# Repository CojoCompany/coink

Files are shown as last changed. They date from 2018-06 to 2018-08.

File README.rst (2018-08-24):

Coink logo

Coink
=====

An IoT piggy bank.

Read `the documentation <https://coink.readthedocs.io/>`_ to know how it works
and how to build your own Coink!

`See Coink in action! <https://www.youtube.com/watch?v=FcyVjBXFm-M>`_



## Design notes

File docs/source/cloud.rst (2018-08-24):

.. index:: cloud

*****************
Cloud integration
*****************

.. index:: flashing

Flashing the NodeMCU
====================

Before running our cloud server, we definitely want to actually upload the
Coink MicroPython code to the NodeMCU board.

This is actually very simple, but we do need to have some dependencies
installed: ``screen`` and ``ampy``. Once we have those, we can simply connect
our board to our computer with an USB cable and::

   ./flash.sh

This Bash script will upload all the necessary code to our board.

.. index:: coink-server

Coink server
============

Running the Coink server is necessary to appropriately process the data and
classify the coins in "the cloud", whether it is your own computer or an actual
cloud service.

The server is implemented with `Flask`_ and requires some other Python packages
to run. Fortunately, `Pipenv`_ helps us to create the required virtual environment with all dependencies installed::

   pipenv sync

If we want to have all the development dependencies installed, use instead::

   pipenv sync --dev

Our prototype is designed to work within a local area network, where we have
the NodeMCU and our computer connected to the same WiFi network (probably our
home network). In order to be able to do so, we need to copy the contents of
the ``config.template.json`` to a new ``config.json`` file, that would look
like this:

.. literalinclude:: ../../config.template.json

We need to modify the ``"wifi"`` fields with our network name and password.

Note that there is another section to configure the ``"server"``. There, we
need to put our computer IP address and a port, where our server will be
listening on.

.. note:: The access port should be just a free port, try it for example with
   5000

Then we can run the server with Pipenv::

   pipenv run python server.py

If everything went well, you should be able to access the configured server
with your web browser. To do so, visit
``http://your-defined-host:your-defined-port/`` (i.e.:
``http://192.168.43.110:5000/``), you should see the Coink server page:

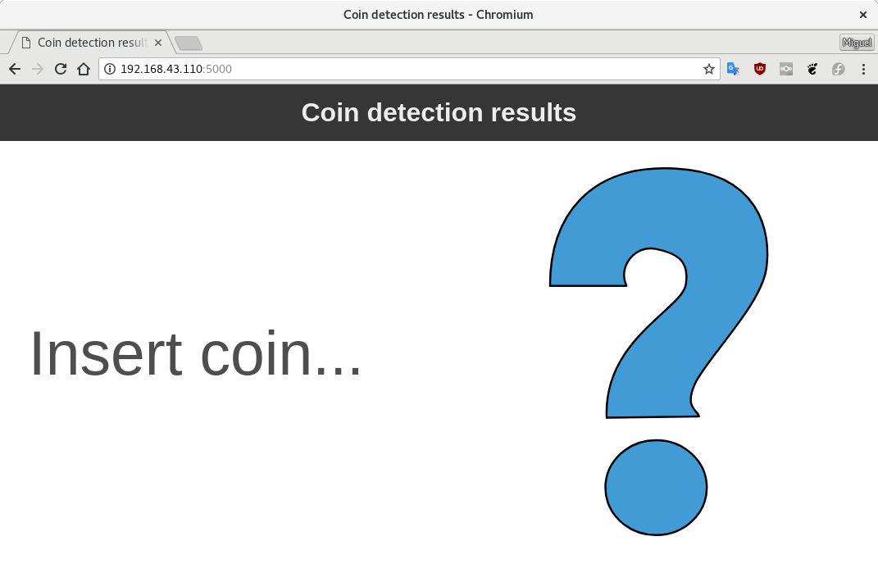
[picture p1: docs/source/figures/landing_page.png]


   Coink landing page.

Now go ahead and insert one coin into your Coink! ^^

.. raw:: html

   <div style="position: relative; padding-bottom: 60%; height: 0;">
     <iframe src="https://www.youtube-nocookie.com/embed/FcyVjBXFm-M?rel=0" frameborder="0" allow="autoplay; encrypted-media" allowfullscreen width="100%" style="position: absolute; top: 0; left: 0; width: 100%; height: 100%">
     </iframe>
   </div>

.. index:: thingspeak

Thingspeak
==========

Integrating Coink with an external cloud service like Thingspeak is very
straight forward thanks to their public RESTful API. We just need to write a
couple of lines of code to process and visualize the data appropriately.

The following code snippet plots the daily savings in the last couple of days:

.. code:: matlab

   [data, time] = thingSpeakRead(516536, 'Fields', [1], 'NumDays', 7);
   data = timetable(time, data)
   data = retime(data, 'daily', 'sum')
   bar(data.time, data.Variables, 'FaceColor', [1 .5 0])

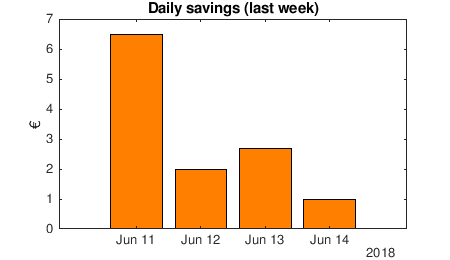
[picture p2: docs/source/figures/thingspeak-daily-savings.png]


The following code snippet plots the total accumulated savings:

.. code:: matlab

   [data, time] = thingSpeakRead(516536, 'Fields', [1], 'NumDays', 365);
   curve = cumsum(data);
   area(time, curve, 'FaceColor', [1 .5 0]);
   title(strcat('Total savings: ', num2str(sum(data), '%.2f'), ' €'));
   ylabel('€');

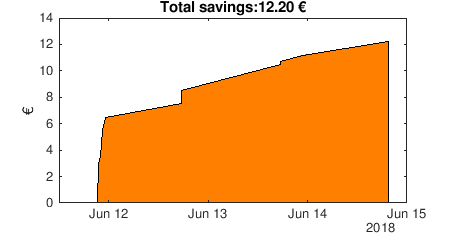
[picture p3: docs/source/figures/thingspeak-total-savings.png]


Note that the code above assumes that the Thingspeak channel was created to
ingest a single field, which corresponds to the coin that was detected on
insertion. The code then sums by day or calculates the total cumulated sum.

References
==========

.. target-notes::

.. _`Flask`:
   http://flask.pocoo.org/
.. _`Pipenv`:
   https://pipenv.readthedocs.io/

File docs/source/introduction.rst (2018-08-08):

.. index:: introduction

************
Introduction
************

.. index:: abstract

What is Coink?
--------------

Coink is an IoT piggy bank.

In the 21st Century piggy banks can be very easily connected to the cloud and
become part of the rapidly growing Internet of Things.

Having automatic reports of your savings online is not only very convenient but
can also make saving fun for kids! With Coink you can have real-time graphics
with your cumulative savings as well as the recent daily savings to track your
progress.

Adults may use it as well, not only for fun, but to help them quit smoking, for
example, keeping track of the money they save each day. Or in bars and
restaurants, to keep track of the tips they get each day.

Of course the magnetic coin detection system can be used elsewhere: in vending
machines, arcade game machines... The cloud-connected piggy bank is just an
application.

.. index:: materials

What do we need?
----------------

In order to build Coink, we will need:

- A wooden box.
- A `3D-printed ramp`_.
- A magnet attached to the ramp, that generates a static magnetic field.
- A `3D Magnetic Sensor 2GO`_ board from Infineon, that will detect the changes
  on the magnetic field when a coin passes through the ramp and in between the
  magnet and the sensor.
- An ESP8266-based board, in particular a `NodeMCU development kit`_, that
  reads the data from the 3D magnetic sensor through I2C and sends it through
  WiFi to the cloud.
- A `cloud server`_ that analyzes the raw data and identifies the
  different coins.



   Coink project overview

References
==========

.. target-notes::

.. _`3D-printed ramp`:
   https://github.com/CojoCompany/coink/blob/master/3d/ramp.stl
.. _`3D Magnetic Sensor 2GO`:
   https://www.infineon.com/cms/en/product/sensor/magnetic-position-sensor/3d-magnetic-sensor/tle493d-a2b6-ms2go/
.. _`NodeMCU development kit`:
   https://github.com/nodemcu/nodemcu-devkit-v1.0
.. _`cloud server`:
   https://github.com/CojoCompany/coink

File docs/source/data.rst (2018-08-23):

.. index:: data

****
Data
****

.. index:: visualization

Visualization
=============

If we visualize the sensor readings during one second, when a coin is passing
by, we note that there is little time (around 50 milliseconds) to get useful
data:

.. plot::
   :align: center
   :context:

   from analysis import read_data
   from matplotlib import pyplot

   pyplot.style.use('seaborn')

   read_data('../../data/1-0.csv')[:1].plot()

Each of the axis has a different iddle-state reading, so we can normalize the
readings by first dividing by the average iddle-state reading and then
substracting 1 to have an iddle-state reading of 0 in all axis and also to have
data curves that represent relative variations of the magnetic field instead of
absolute.

After doing this normalization we can visualize our region of interest for both
1 € and 2 € coins:

.. plot::
   :align: center
   :context: close-figs

   from analysis import load_data

   c1 = load_data(1, path='../../data')
   c2 = load_data(2, path='../../data')
   c1[0].plot(title='1 €')
   c2[0].plot(title='2 €')

.. index:: differences

Differences
===========

Having a look at the previous curves we might notice some differences between
the 1 € and 2 € curves. Among them we might notice a small difference in the
time span. Although that makes sense (the 2 € coin has a bigger diameter than
the 1 € coin) and we would expect it to alter the magnetic field for a longer
period, this is assuming the speed is the same for both coins. That, of course,
is not very reliable, as we could simply insert coins with higher speed when
pushing them down the ramp. Therefore, we will ignore differences in the x-axis
(time) and focus on the y-axis (magnetic field relative variations).

In order to be able to compare curves and try to differenciate among different
coins, we did some simple feature engineering to try to extract some curve
features that are relevant and easy to compare/match against known profiles:



   Engineered features.

min_[axis]
  Represents the absolute minimum value, for the given axis.

d0_[axis]
  Represents the maximum positive increase since the last rolling minimum from
  the iddle state and until the absolute minimum is reached, for the given
  axis.

l0_[axis]
  Represents the low value where ``d0_[axis]`` started, for the given axis.

Although the differences for those engineered features might seem obvious for
the curves shown above, we want to make sure that the differences are
significant on average for all the data we gathered.

To visualize these differences we can use box plots for all ``min``, ``l0`` and
``d0`` features, for all axis as well:

.. plot::
   :align: center
   :context: close-figs

   from analysis import compare_d0
   from analysis import compare_l0
   from analysis import compare_min
   from analysis import data_summary

   df = data_summary(c1, c2)
   compare_min(df)
   compare_d0(df)
   compare_l0(df)

We can see there are many significant differences between the two coins.
Although we could use only the most significant among them it is better to
simply use all features. Matching against the average plus some expected
deviation we can not only differenciate between 1 € and 2 € coins, but also
detect unexpected (potentially fake coins) readings.

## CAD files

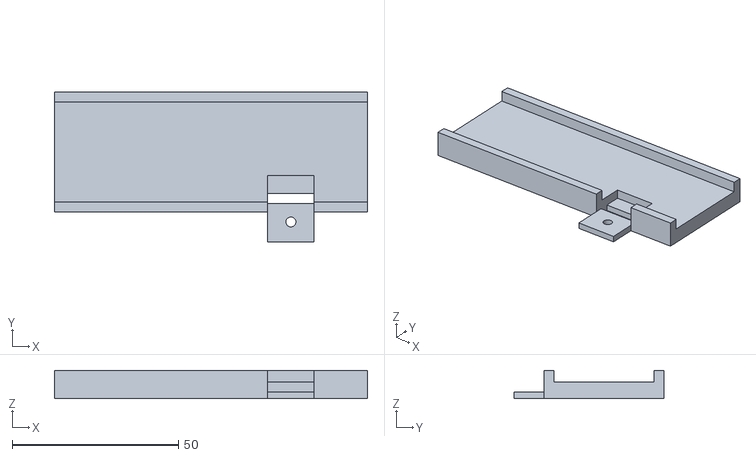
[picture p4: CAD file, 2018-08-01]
3d/ramp.stl
94.0 x 45.0 x 8.50

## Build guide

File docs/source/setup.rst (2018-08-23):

.. index:: setup

*****
Setup
*****

.. index:: board

Board
=====

We use an ESP8266-based board, in particular a `NodeMCU development kit`_.

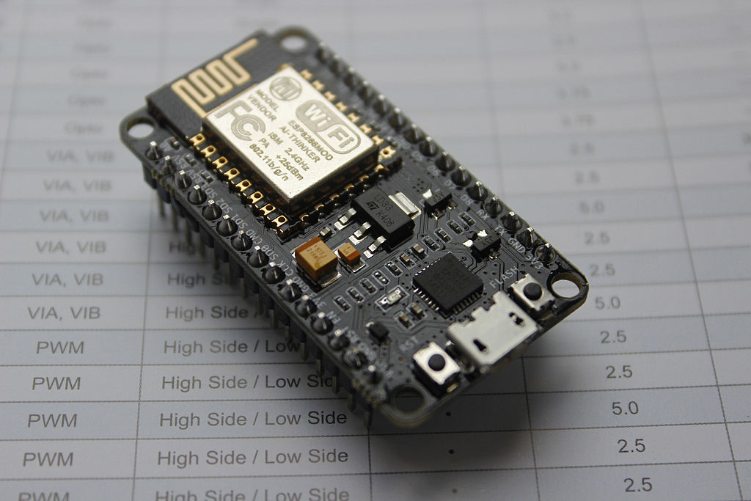
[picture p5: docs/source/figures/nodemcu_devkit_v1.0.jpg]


   NodeMCU development kit.

It is a very cheap, but powerful board.

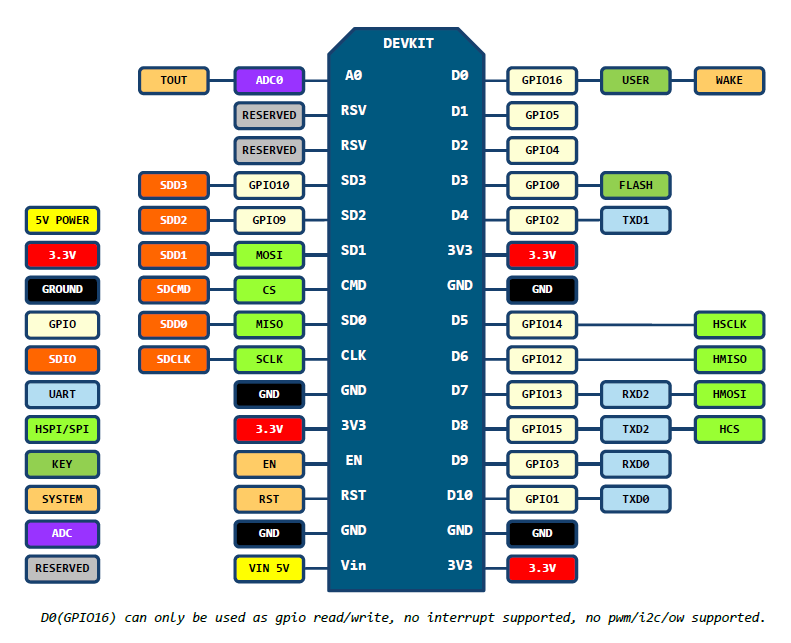
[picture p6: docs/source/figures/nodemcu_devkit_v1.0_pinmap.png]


   NodeMCU development kit pinout.

.. index:: micropython

MicroPython
===========

We use the Python programming language or, more accurately, the `MicroPython`_
programming language. Not only it is a beautiful language, but also implements
an HTTP stack that will ease the process of communicating with a remote server
in any IoT project.

In order to start using MicroPython, we need to `load the MicroPython firmware
onto the ESP8266 board
<https://docs.micropython.org/en/latest/esp8266/esp8266/tutorial/intro.html>`_
first.

Flashing the firmware
---------------------

We need to make sure we have the required permissions to flash the device.
Either::

   sudo usermod -a -G dialout $USER

Or, to avoid the need to log out of your session::

   sudo echo 'ATTRS{idVendor}=="1a86", ATTRS{idProduct}=="7523", MODE="0666"'> /etc/udev/rules.d/99-nodemcu.rules
   sudo udevadm control --reload-rules

.. note:: You might need to adjust the ``idVendor`` and ``idProduct`` depending
   on what you see with ``dmesg`` when connecting the device.

We use `esptool`_ to reflash the device, which is very easy to install with::

   pip install --user esptool

Then, reconnect the device and erase its flash memory with::

   esptool.py --port /dev/ttyUSB0 erase_flash

Download the `latest MicroPython firmware for ESP8266 boards
<https://micropython.org/download#esp8266>`_ and flash it with::

   esptool.py --port /dev/ttyUSB0 --baud 460800 write_flash --flash_size=detect 0 esp8266-20180511-v1.9.4.bin

Testing the REPL
----------------

Once the MicroPython firmware is on the device we can access the REPL (Python
prompt) over serial with a 115000 baudrate::

   screen /dev/ttyUSB0 115200

If everything went well we should see a ``>>>`` (if not, try to press "enter").
You may now try to execute a simple ``print()`` call, which will be executed in
the board itself:



   MicroPython REPL.

.. index:: sensor

Sensor
======

The ESP8266 board is connected to the sensor through an I2C bus, in particular,
using D1 (GPIO5) for the clock and D2 (GPIO4) for the data transmission. The
sensor is powered with the ESP8266 board directly, using its 3V3 and GND pins.

Once the sensor is connected to the board we can check the I2C connection by
simply:

.. code:: python

   from machine import I2C
   from machine import Pin

   i2c = I2C(scl=Pin(5), sda=Pin(4), freq=400000)
   devices = i2c.scan()
   print(devices)

Which should print a non-empty list.

References
==========

.. target-notes::

.. _`esptool`:
   https://github.com/espressif/esptool/
.. _`MicroPython`:
   https://docs.micropython.org/
.. _`NodeMCU development kit`:
   https://github.com/nodemcu/nodemcu-devkit-v1.0

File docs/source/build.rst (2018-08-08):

.. index:: build

*****
Build
*****

.. index:: ramp

Ramp
====

Coink is actually very easy to build. First we need the ramp to insert the
coins. The ramp is a 3D design that can be very easily printed with any FDM 3D
printer (or any other more-advance 3D printer if you have access to it).

.. raw:: html

   <div style="position: relative; padding-bottom: 60%; height: 0;">
     <iframe src="https://render.githubusercontent.com/view/solid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" width="100%" style="position: absolute; top: 0; left: 0; width: 100%; height: 100%">
     </iframe>
   </div>

The 3D design is very simple but, in turn, we need to do some work before using
it. First, we need to glue some plastic sheets to cover the inner parts of the
ramp. This way we avoid the coin bumping into any disturbances around the
sensor board, where the ramp is not continuous:

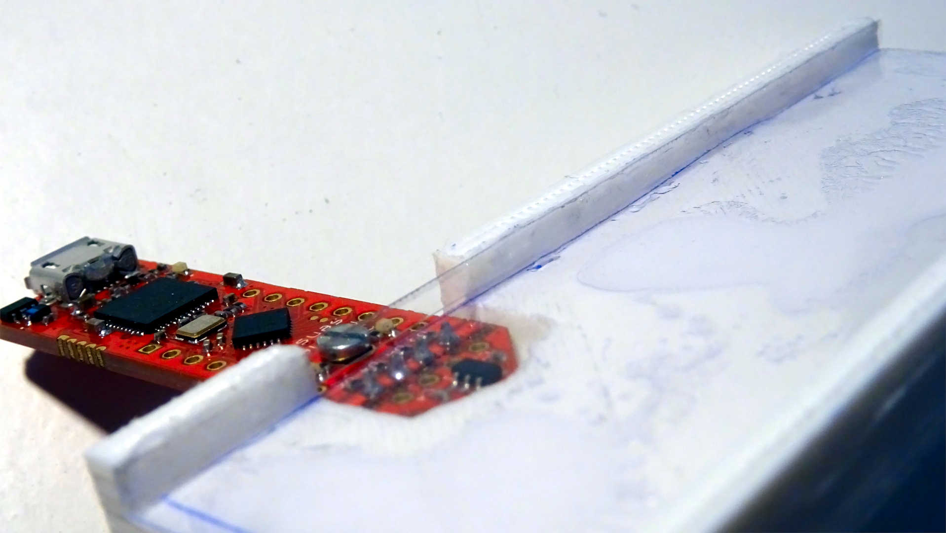
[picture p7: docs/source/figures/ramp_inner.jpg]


   Plastic sheets covering the inner parts of the ramp.

Then we need to cover the outter part of the ramp by glueing another plastic
sheet. We will glue our magnet (in orange) there, just in front of the sensor
board. Any magnet will do, we just need to make sure it is not too powerful, or
the coins will get stuck in the ramp!

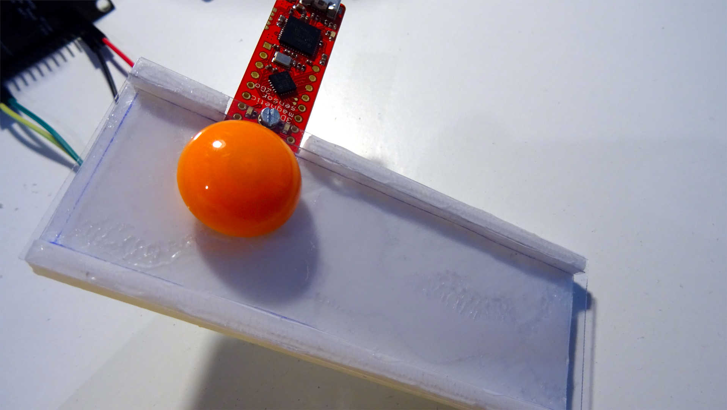
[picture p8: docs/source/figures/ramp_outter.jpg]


   Plastic sheet covering the outter part of the ramp and magnet attached to
   it.

.. index:: box

Box
===

The piggy bank can be made with a small wooden box. Wood is easy to work with,
which is important as we will need to create a hole for the ramp in the box:

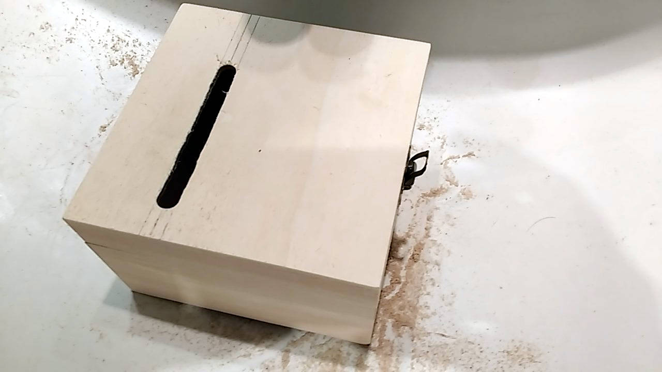
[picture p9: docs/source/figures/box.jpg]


   Wooden box with a hole for the ramp.

Once we have the hole, we can very easily glue the ramp to the box with some
epoxy to make sure it does not move.

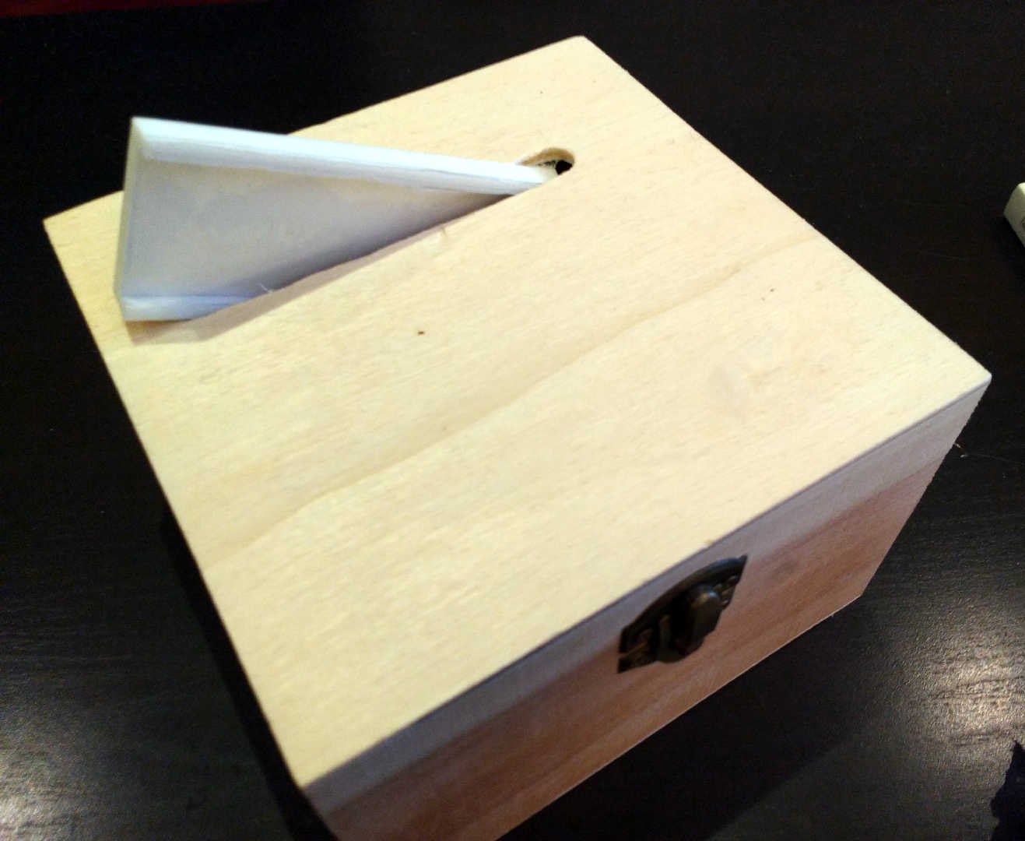
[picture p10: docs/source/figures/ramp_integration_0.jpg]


   Ramp glued to the box.

Even if obvious, we should make sure the magnet and the magnetic sensor board
both fit inside the box before glueing the ramp!

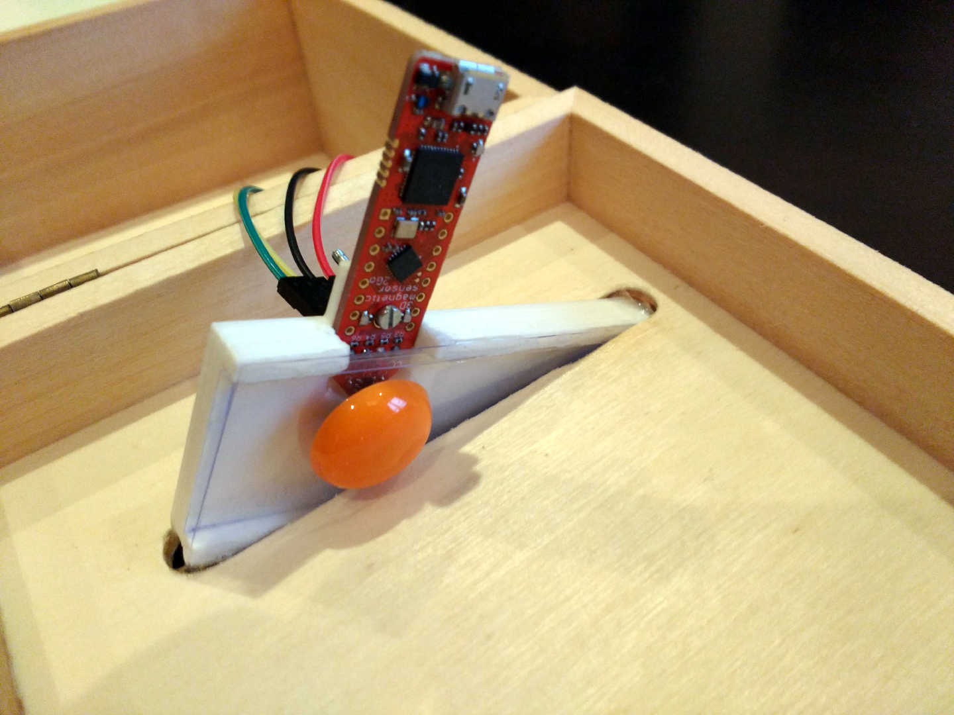
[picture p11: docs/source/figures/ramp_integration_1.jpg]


   Detail of the ramp inside the box.

Once the ramp is fixed, we only need to stick the rest of the components to the
lid:

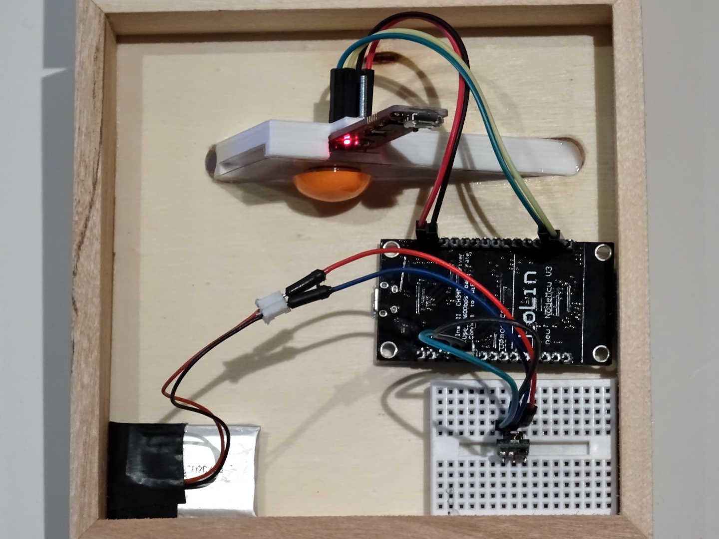
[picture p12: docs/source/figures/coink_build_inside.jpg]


   All the required components fixed and the system powered!

Note that we added a simple power circuit consisting of:

- A LiPo battery (single cell).
- A 3.3 V step-down DC-DC converter mounted on the breadboard.

The output of the converter directly powers the board at 3.3 V.

.. index:: wiring

Wiring
======

Wiring the magnetic sensor board and the NodeMCU boils down to connect only 4 wires:

===========  ===================
NodeMCU pin  Magnetic sensor pin
===========  ===================
D1 (GPIO5)   SDA (P2.10)
D2 (GPIO4)   SCL (P2.11)
3V3          3V3 (P1.0)
GND          GND
===========  ===================

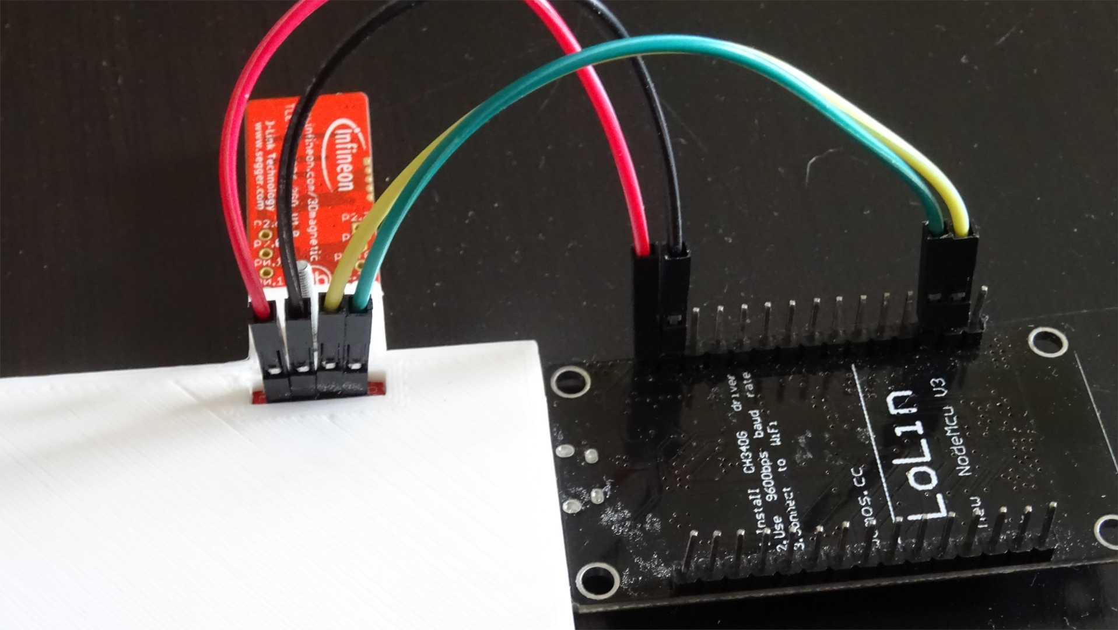
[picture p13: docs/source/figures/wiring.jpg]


   NodeMCU and magnetic sensor wiring.

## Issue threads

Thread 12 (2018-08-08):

Document battery connection

cua-cua, 2018-08-08:
http://henrysbench.capnfatz.com/henrys-bench/arduino-projects-tips-and-more/powering-the-esp-12e-nodemcu-development-board/

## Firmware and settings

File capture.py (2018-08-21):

import json
import sys
import time
import array

import urequests

import machine
from machine import I2C
from machine import Pin
from machine import Signal
from network import WLAN
from network import STA_IF


scan_address = 53

write_address = 0x6a
read_address = 0x6b

register_config = 0x10
register_mod1 = 0x11

reply = bytearray(7)
trigger = 1 << 7
request = bytearray([read_address, trigger + 0x00])

num_measures= 256

ring = array.array('h', (0 for i in range(4 * num_measures)))


def twos_complement(val, bits):
    if (val & (1 << (bits - 1))) != 0:
        val = val - (1 << bits)
    return val


def read_registers(i2c):

    i2c.start()
    ack = i2c.write(request)
    i2c.readinto(reply)
    i2c.stop()

    return reply, ack


def write_register(i2c, register, value):
    """
    Write a register with the given value.
    """
    message = bytearray([write_address, register, value])
    i2c.start()
    ack = i2c.write(message)
    i2c.stop()
    if not ack == 3:
        message = 'Writing register failed after {} bytes!\n'
        sys.stderr.write(message.format(ack))


def read_sensor(i2c):
    reply, ack = read_registers(i2c)

    x_high = reply[0]
    x_low = (reply[4] >> 4)
    y_high = reply[1]
    y_low = (reply[4] & 0x0F)
    z_high = reply[2]
    z_low = (reply[5] & 0x0F)
    t_high = reply[3]
    t_low = (reply[5] >> 6)

    x = twos_complement((x_high << 4) + x_low, 12)
    y = twos_complement((y_high << 4) + y_low, 12)
    z = twos_complement((z_high << 4) + z_low, 12)
    t = twos_complement((t_high << 2) + t_low, 10)

    return reply, (x, y, z, t), ack


def get_sensor_values(i2c):
    for i in range(100):
        reply, readings, ack = read_sensor(i2c)
        status = reply[6]
        pd0 = bool(status & 0b100)
        if not pd0:
            message = 'Power-down flag 0 (PD0) was zero! Retrying...\n'
            sys.stderr.write(message.format(ack))
            continue
        pd3 = bool(status & 0b1000)
        if not pd3:
            message = 'Power-down flag 3 (PD3) was zero! Retrying...\n'
            sys.stderr.write(message.format(ack))
            continue
        tbit = bool(status & 0b10000)
        if tbit:
            message = 'T-bit was one! Retrying...\n'
            sys.stderr.write(message.format(ack))
            continue
        frame_counter = status & 0b11
        break
    return reply, readings, ack, i, pd0, frame_counter


class Node:
    def __init__(self):
        """
        Initialize the node.

        Performs the hardware setup and configuration loading from
        `config.json` file.
        """
        machine.freq(160000000)

        self.led = Signal(Pin(2, Pin.OUT), invert=True)
        self.led.off()

        self.i2c = I2C(scl=Pin(5), sda=Pin(4), freq=400000)

        self.station = WLAN(STA_IF)

        self.config = json.load(open('config.json'))

        self.countdown = None

    def setup_sensor(self):
        """
        Configure the sensor to use Master Controlled Mode.

        Also, enable clock stretching and disable interruptions. Sensor read
        out is suppressed during ongoing ADC conversions.

        Returns
        -------
        The number of acklowledges the sensor sent back. Should be 3.
        """
        devices = self.i2c.scan()
        if not scan_address in devices:
            message = 'Sensor "{}" does not seem to be available!\n'
            sys.stderr.write(message.format(scan_address))
            return

        write_register(self.i2c, register_config, 0b00001001)
        write_register(self.i2c, register_mod1, 0b10000101)

    def connect_wifi(self):
        """
        Connect the node to a wireless network.

        The wireless network must be defined in the `config.json` file.
        """
        self.station.active(True)
        config = self.config['wifi']
        self.station.connect(config['ssid'], config['password'])
        for i in range(10):
            if self.station.isconnected():
                break
            sys.stdout.write('Waiting for connection to be established...\n')
            time.sleep(1)
        else:
            message = 'Could not establish connection...\n'
            sys.stderr.write(message.format(ack))
            led.on()

    def update_savings(self, savings):
        """
        Update the remote servers with the new savings.
        """
        url = 'https://api.thingspeak.com/update'
        url += '?api_key={key}&field1={savings}'
        url = url.format(key=self.config['thingspeak_key'], savings=savings)
        reply = urequests.get(url)
        return reply

    def send_readings(self):
        """
        Send magnetic sensor values from a file to the server detailed
        on the file config.json.
        """
        url = 'http://{host}:{port}/analyze'.format(**self.config['server'])
        response = urequests.post(url, data=bytearray(ring))

    def callibrate(self):
        """
        Callibrate the sensor and set the threshold for coin detection.
        """
        total = 0
        count = 10
        for i in range(count):
            reply, (x, y, z, t), ack = read_sensor(self.i2c)
            total += x
        self.threshold = 0.8 * total / count

    def loop(self):
        """
        Read and send coin values forever.
        """
        i = 0
        while True:
            i = i % num_measures
            reply, (x, y, z, t), ack = read_sensor(self.i2c)
            # Make sure we never try to store a value higher than the size of
            # the `t_array` elements
            position = i * 4
            ring[position] = time.ticks_us() % 65536
            ring[position + 1] = x
            ring[position + 2] = y
            ring[position + 3] = z
            if self.countdown is None:
                if x < self.threshold:
                    self.countdown = 150
            else:
                self.countdown -= 1
                if self.countdown == 0:
                    print('Sending readings...')
                    self.send_readings()
                    print('Readings sent!')
                    self.countdown = None
            i += 1

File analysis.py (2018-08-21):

import numpy
import pandas
from pathlib import Path


def raw_to_dataframe(raw):
    data = numpy.frombuffer(raw, dtype='int16')
    data = data.reshape((data.size // 4, 4))
    df = pandas.DataFrame(data, columns=['t', 'x', 'y', 'z'])

    # Center the curve
    shift = len(df) // 2 - df['x'].idxmin()
    df = df.reindex(numpy.roll(df.index, shift)).reset_index(drop=True)

    df['t'] = df['t'].diff().cumsum() * 1e-6
    df.loc[0, 't'] = 0.
    df = df.set_index('t')
    return df


def read_data(fname):
    df = pandas.read_csv(fname, dtype='h')
    df['t'] = df['t'].diff().cumsum() * 1e-6
    df.loc[0, 't'] = 0.
    df = df.set_index('t')
    return df


def normalize(df):
    df = df.astype(float)
    df /= df.iloc[:50].mean()
    df -= 1
    zone = df[df['x'] < -0.2]
    diff = zone.index[-1] - zone.index[0]
    t0 = zone.index[0] - diff
    t1 = zone.index[-1] + diff
    df = df[t0:t1]
    df.index -= df.index[0]
    return df


def load_data(coin, path: Path = None):
    if path is None:
        path = Path('data')
    if isinstance(path, str):
        path = Path(path)
    data = []
    for fname in path.glob('%s-*.csv' % coin):
        df = read_data(fname)
        df = normalize(df)
        data.append(df)
    return data


def axis_features(curve):
    diff = 0
    low = curve[0]
    d0_low = low
    for value in curve:
        low = min(low, value)
        d = value - low
        if d > diff:
            diff = d
            d0_low = low
        if value == curve.min():
            break
    return {'min': curve.min(), 'l0': d0_low, 'd0': diff}


def summary(curve, coin):
    x = axis_features(curve['x'])
    y = axis_features(curve['y'])
    z = axis_features(curve['z'])
    summary = {
        'coin': coin,
        'min_x': x['min'],
        'min_y': y['min'],
        'min_z': z['min'],
        'l0_x': x['l0'],
        'l0_y': y['l0'],
        'l0_z': z['l0'],
        'd0_x': x['d0'],
        'd0_y': y['d0'],
        'd0_z': z['d0'],
    }
    return summary


def data_summary(c1, c2):
    data = zip(c1 + c2, ['1 €'] * 10 + ['2 €'] * 10)
    return pandas.DataFrame([summary(curve, coin) for curve, coin in data])


def compare_min(df):
    df.boxplot(['min_x', 'min_y', 'min_z'], by='coin',
               layout=(1, 3), figsize=(12, 6))


def compare_d0(df):
    df.boxplot(['d0_x', 'd0_y', 'd0_z'], by='coin',
               layout=(1, 3), figsize=(12, 6))


def compare_l0(df):
    df.boxplot(['l0_x', 'l0_y', 'l0_z'], by='coin',
               layout=(1, 3), figsize=(12, 6))


def classify_coin(curve):
    features_x = axis_features(curve['x'])
    if -0.40 > features_x['min'] > -0.55:
        return 1
    if -0.55 > features_x['min'] > -0.75:
        return 2
    return -1

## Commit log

2018-06-08 Add initial board setup documentation
2018-06-08 Add script to communicate with the magnetic sensor
2018-06-08 Extract the x/y/z components and temperature
2018-06-08 Configure sensor before reading it
2018-07-05 Add simple scripts to flash and connect to device
2018-07-06 Allow saving sensor readings to a file
2018-07-06 Increase sensor sensivity
2018-08-01 Add ramp 3d file
    [ramp.stl]
2018-08-01 Save timestamps when capturing sensor data
2018-08-01 Add data visualization notebook
    [1-0.csv, 1-1.csv, 1-2.csv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]
2018-08-17 Send readings from the board to a server
2018-08-17 Server code to receive data from the board
